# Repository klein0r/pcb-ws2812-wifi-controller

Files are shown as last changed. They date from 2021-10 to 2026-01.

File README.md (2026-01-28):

# WS2812 / SK6812 Wifi Controller Custom PCB

Control your addressable LED with custom software like [WLED](https://github.com/Aircoookie/WLED)

[Gerber-Files](https://github.com/klein0r/pcb-ws2812-wifi-controller/releases)

## Preview

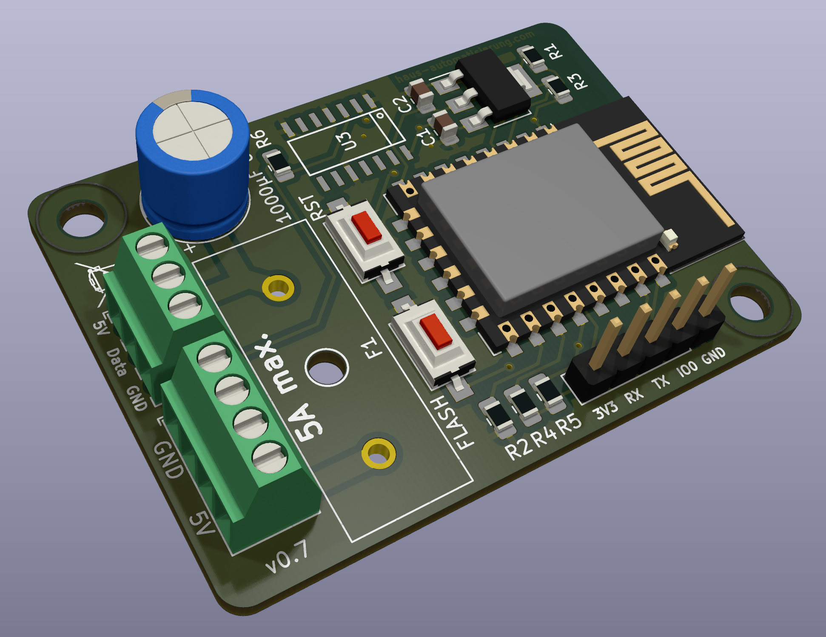
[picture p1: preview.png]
PCB Preview


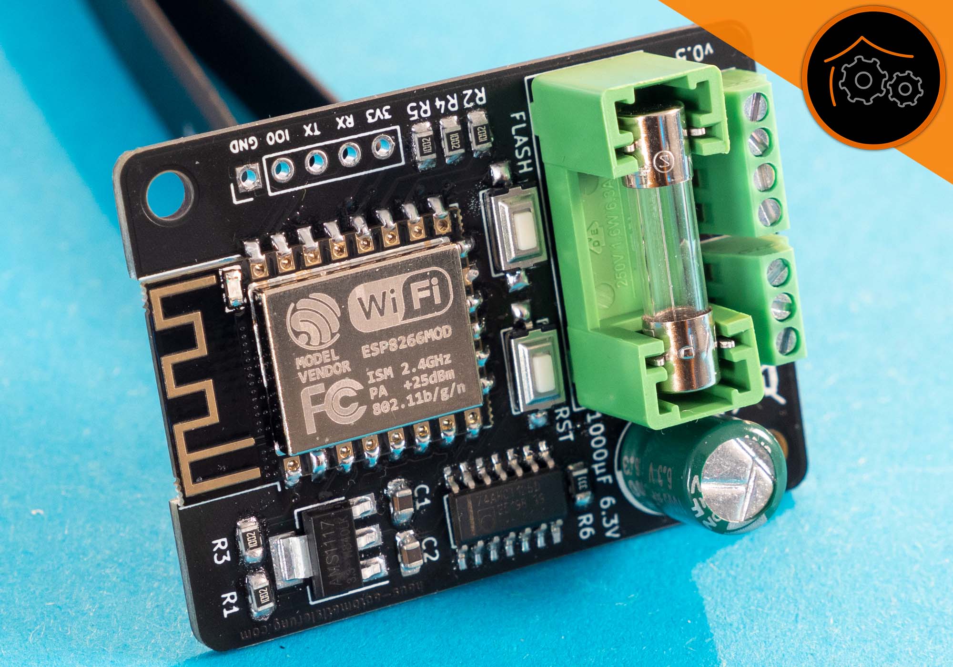
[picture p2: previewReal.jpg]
PCB Photo


## Components

- C1, C2: Capacitor 0805 100nF
- C3: Capacitor Radial 3.8mm 1000μF 6.3
- F1: Stelvio Kontek STV PTF/75 + Fuse 5x20mm, 5A (max. 6A)
- J1: PHC 1725672 - MPT 0,5 / 4-2,54
- J2: 1x5 2.54mm Male Pin Headers (for flashing - soldering not required)
- J3: PHC 1725669 - MPT 0,5 / 3-2,54
- R1, R2, R3, R4, R5: Resistor 0805 10k
- R6: Resistor 0805 330
- SW1, SW2: Push Button 3*6*2.5mm
- U1: AMS1117-3.3 SOT 223
- U2: ESP-12F
- U3: SN74AHCT125DR

## GPIO

- GPIO4 = Data line of addressable strip

## Cases

- [Case by DrNuke33](https://www.thingiverse.com/thing:4909109)

## Older Versions

*See git tag / releases*

**0.1**

PCB Preview

**0.2**

PCB Preview

**0.3**

PCB Preview

**0.4**

PCB Preview

## License

The MIT License (MIT)

Copyright (c) 2026 Matthias Kleine <info@haus-automatisierung.com>

Permission is hereby granted, free of charge, to any person obtaining a copy
of this software and associated documentation files (the "Software"), to deal
in the Software without restriction, including without limitation the rights
to use, copy, modify, merge, publish, distribute, sublicense, and/or sell
copies of the Software, and to permit persons to whom the Software is
furnished to do so, subject to the following conditions:

The above copyright notice and this permission notice shall be included in
all copies or substantial portions of the Software.

THE SOFTWARE IS PROVIDED "AS IS", WITHOUT WARRANTY OF ANY KIND, EXPRESS OR
IMPLIED, INCLUDING BUT NOT LIMITED TO THE WARRANTIES OF MERCHANTABILITY,
FITNESS FOR A PARTICULAR PURPOSE AND NONINFRINGEMENT. IN NO EVENT SHALL THE
AUTHORS OR COPYRIGHT HOLDERS BE LIABLE FOR ANY CLAIM, DAMAGES OR OTHER
LIABILITY, WHETHER IN AN ACTION OF CONTRACT, TORT OR OTHERWISE, ARISING FROM,
OUT OF OR IN CONNECTION WITH THE SOFTWARE OR THE USE OR OTHER DEALINGS IN
THE SOFTWARE.

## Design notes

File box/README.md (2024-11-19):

# Print parts 

## Preview

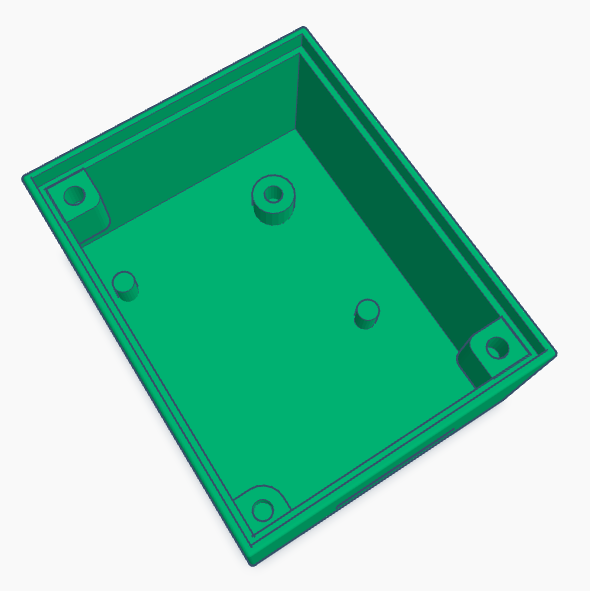
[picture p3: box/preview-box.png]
Box v3

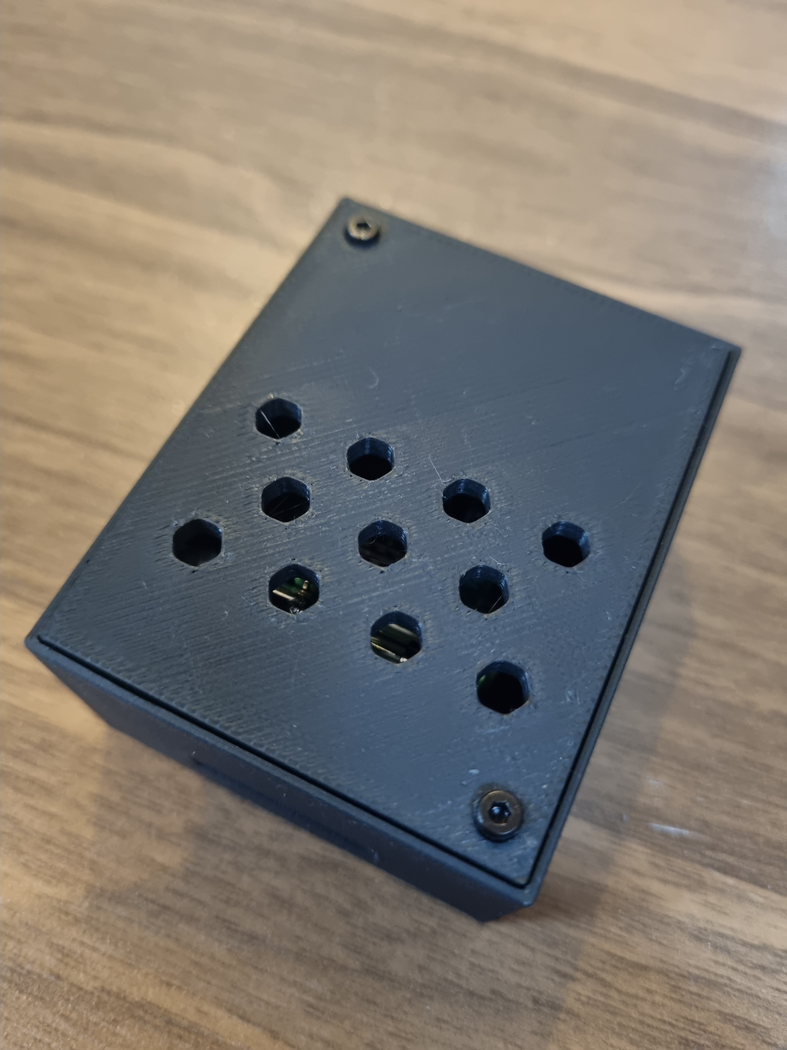
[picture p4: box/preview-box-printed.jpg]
Box printed


## Components

- 4x Melting nut M2x4.0
- 4x Screw M2x4

## Changelog

### 2024-05-17

#### Added

- box-v2 Base box model without supports for the board. When tighten the screws sometimes the board happens to tilt slightly
- box-v3 Improved version of v2, should stop the board from tilting. This model hasn't been prototyped yet
- box-cover-v2 A cover to close the box

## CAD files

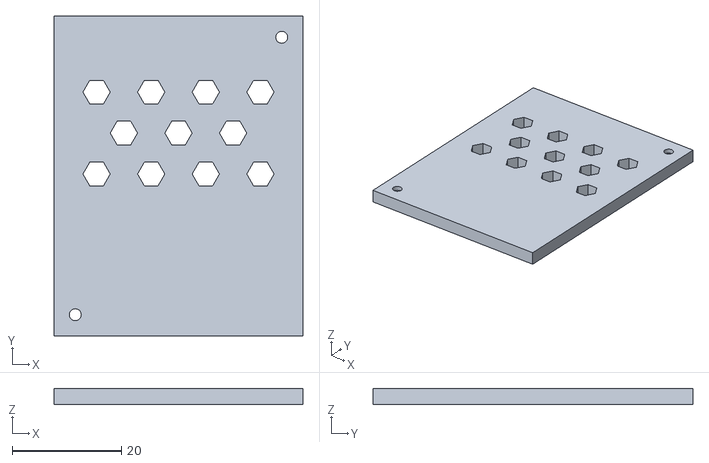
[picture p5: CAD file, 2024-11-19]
box/box-cover-v2.stl
45.6 x 58.6 x 3.00

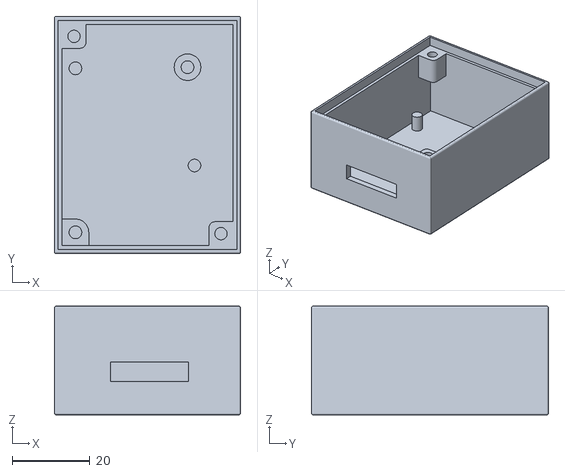
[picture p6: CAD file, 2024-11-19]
box/box-v3.stl
48.0 x 61.0 x 28.0

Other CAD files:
box/box-v2.stl

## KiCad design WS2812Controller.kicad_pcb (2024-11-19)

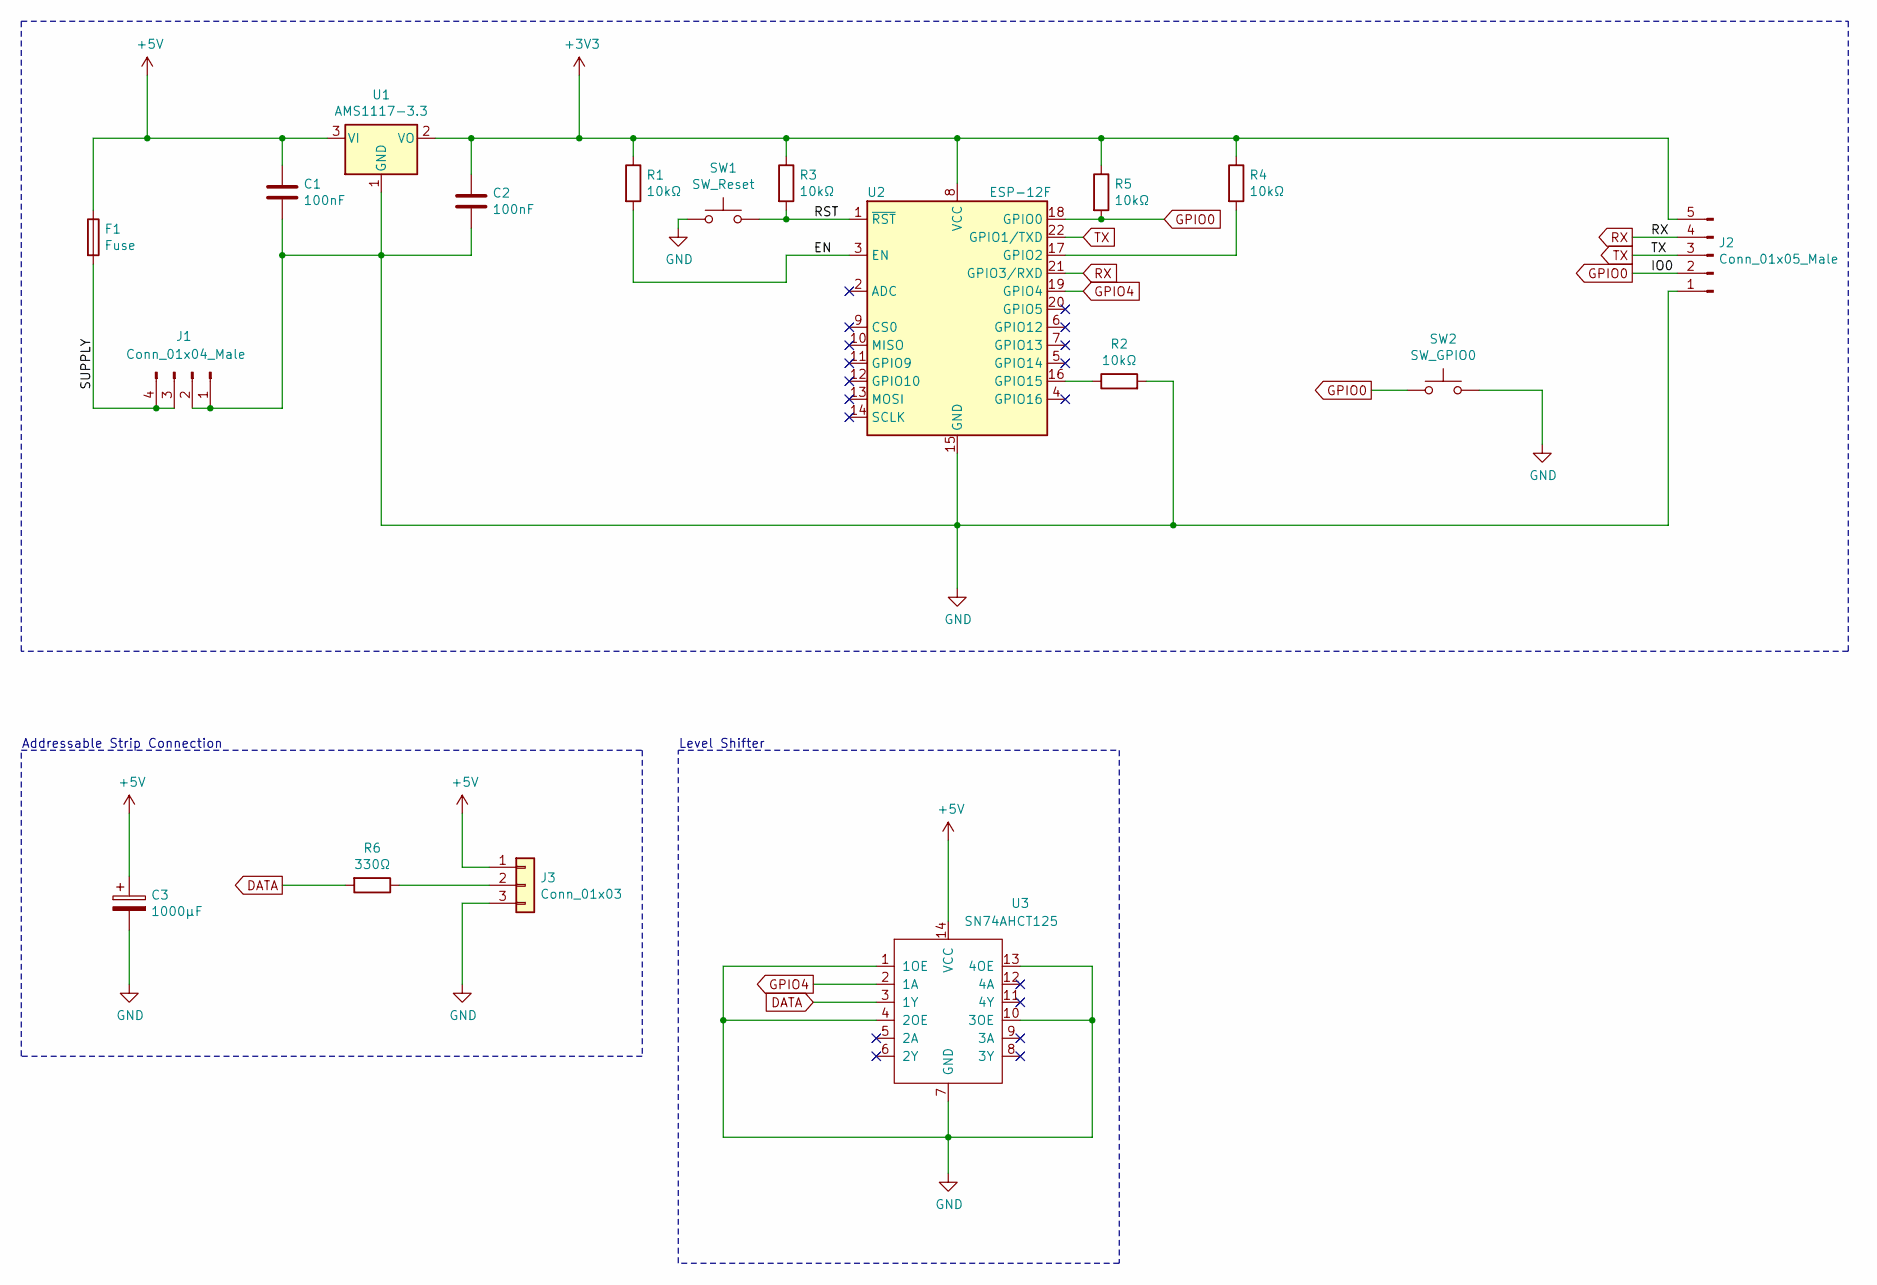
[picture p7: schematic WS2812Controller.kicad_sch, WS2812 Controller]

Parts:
C1, C2: 100nF; C_0805_2012Metric_Pad1.15x1.40mm_HandSolder
C3: 1000µF; CP_Radial_D8.0mm_P3.80mm
F1: Fuse; Fuse-PTF75_Stelvio
J1: Conn_01x04_Male; TerminalBlock_Phoenix_MPT-0,5-4-2.54_1x04_P2.54mm_Horizontal
J2: Conn_01x05_Male; PinHeader_1x05_P2.54mm_Vertical
J3: Conn_01x03; TerminalBlock_Phoenix_MPT-0,5-3-2.54_1x03_P2.54mm_Horizontal
R1, R2, R3, R4, R5: 10kΩ; R_0805_2012Metric_Pad1.15x1.40mm_HandSolder
R6: 330Ω; R_0805_2012Metric_Pad1.15x1.40mm_HandSolder
SW1: SW_Reset; SW_SPST_CK_RS282G05A3
SW2: SW_GPIO0; SW_SPST_CK_RS282G05A3
U1: AMS1117-3.3; SOT-223-3_TabPin2
U2: ESP-12F; ESP-12E
U3: SN74AHCT125; SN74AHCT125D

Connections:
+3V3: C2.1, J2.5, R1.1, R3.1, R4.1, R5.1, U1.2 (VO), U2.8 (VCC)
+5V: C1.1, C3.1, F1.1, J3.1, U1.3 (VI), U3.14 (VCC)
/EN: R1.2, U2.3 (EN)
/RST: R3.2, SW1.2, U2.1 (~RST)
/SUPPLY: F1.2, J1.3, J1.4
DATA: R6.2, U3.3 (1Y)
GND: C1.2, C2.2, C3.2, J1.1, J1.2, J2.1, J3.3, R2.2, SW1.1, SW2.2, U1.1 (GND), U2.15 (GND), U3.1 (1OE), U3.4 (2OE), U3.7 (GND), U3.10 (3OE), U3.13 (4OE)
GPIO0: J2.2, R5.2, SW2.1, U2.18 (GPIO0)
GPIO4: U2.19 (GPIO4), U3.2 (1A)
unnamed: J3.2, R6.1
unnamed: R2.1, U2.16 (GPIO15)
unnamed: R4.2, U2.17 (GPIO2)
RX: J2.4, U2.21 (GPIO3/RXD)
TX: J2.3, U2.22 (GPIO1/TXD)

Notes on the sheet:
Addressable Strip Connection
Level Shifter

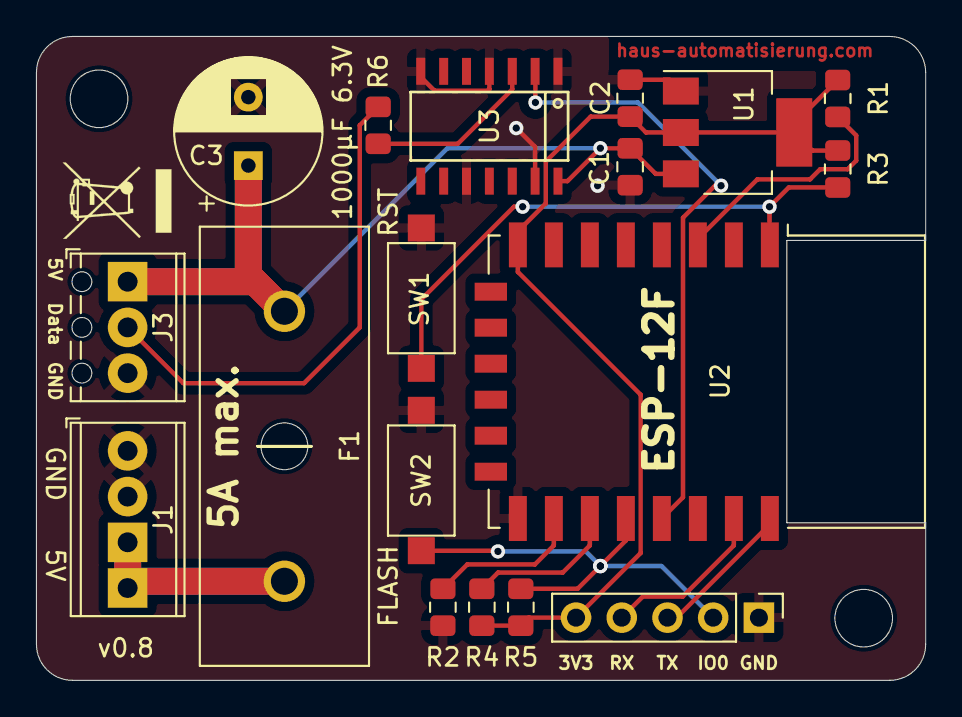
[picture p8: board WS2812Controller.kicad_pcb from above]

Board: 2 copper layers, 49.4 x 35.8 mm, 18 parts (0 on the bottom side), 14 nets.

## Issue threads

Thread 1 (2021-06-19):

some upgrades for the Board

MaBe15, 2021-06-19:
Hi @klein0r,
erstmal danke für die super Arbeit mit der Platine, ich werde mir ein paar fertigen lassen.
Mir sind einge Kleinigkeiten aufgefallen, die ich für meine eigene Bestellung geändert habe, vlt. möchtest du die ja auch ändern:

- Leiterbahnbreite für das Supply-Netz und 5V-Netz vergrößert. Die 0,5mm sind zu gering um die 5A führen zu können bis die Sicherung fällt. [IPC2221](https://www.multi-circuit-boards.eu/leiterplatten-design-hilfe/oberflaeche/leiterbahn-strombelastbarkeit.html)
- Stützkondensatoren für den ESP wie im Datenbaltt beschrieben
- Glättungskondensatoren des Linearreglers an die Werte im Datenblatt angepasst
[pcb-ws2812-wifi-controller-upgrade-main.zip](https://github.com/klein0r/pcb-ws2812-wifi-controller/files/6680438/pcb-ws2812-wifi-controller-upgrade-main.zip)

Ansonsten ist das eine super Platine, danke dafür.
Gruß
Marcus

MaikPerezHeide, 2021-07-06:
Hallo Marcus, ist  es möglich, in Deinem Entwurf, den ESP 12F einfach 1:1 gegen einen ESP32-WROOM32D auszutauschen, oder muss da ggf. noch etwas an der Verkabelung geändert werden? Ich bin neu in diesem Bereich, habe auch wenig Ahnung von Elektronik. Ich würde aber gerne den ESP32 für dieses Projekt verwenden. Vielen Dank im Voraus.
Gruß
Maik

MaBe15, 2021-07-06:
Hallo Maik,
wenn ich es auf die schnelle richtig gesehen habe, dann stimmen die mechanischen Abmessungen des ESP32-WROOM32D mit denen des ESP12F nicht überein. Auch die Anzahl PINs und die Pinbelegung ist nicht identisch. Ein 1:1 Austausch ist also nicht möglich. Du müsstest also den Schaltplan und das Routing auf dem PCB komplett überarbeiten.

Gruß
Marcus

Philip52, 2021-12-29:
@MaBe15
Hi. Danke für dein Update. Ich wollte es gerade bei jlcpcb in Auftrag geben aber die können die Datei nicht öffnen. Hattest du das Problem auch oder hab ich evtl n Fehler gemacht. Grüße
Philip

nocodeman55, 2022-02-16:
> Hallo Marcus, ist es möglich, in Deinem Entwurf, den ESP 12F einfach 1:1 gegen einen ESP32-WROOM32D auszutauschen, oder muss da ggf. noch etwas an der Verkabelung geändert werden? Ich bin neu in diesem Bereich, habe auch wenig Ahnung von Elektronik. Ich würde aber gerne den ESP32 für dieses Projekt verwenden. Vielen Dank im Voraus.
> Gruß
> Maik
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

Sorry i need to reply in English

I found this module ESP-C3-12F Module

This might work - it have the same size and is ESP32 - should drop in - but im not sure about the needed pins?

Closed 2021-12-29.

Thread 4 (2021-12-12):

Kurzes Update ?

Xorfee, 2021-12-12:
Hey gibt es eventuell ne Möglichkeit den GPIO4 pin auf gpio3 zu ändern ? Weil ich gerne die Platine mit diyhue betreiben möchte und die nur gpio3 unterstützen

klein0r, 2021-12-29:
Einfach selbst mit KiCad im Schema anpassen und exportieren.

Closed 2021-12-29.

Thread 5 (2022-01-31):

Assembly ?

bangboomben, 2022-01-31:
Hi,

newbie-question: do the boards come pre-assembled with all the parts ?
If not, do I require any extra file for JLCPCB ?

Cheers
Ben

klein0r, 2022-01-31:
I always order the plain PCB without parts and solder them on my own.

There is also a service where you can order pre-assembled PCB. But: I haven't provided a file in this repository which component belongs to which location in which orientation...

Closed 2022-01-31.

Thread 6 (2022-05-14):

SN74AHCT125DR and AMS1117-3.3 not/hardly available (looking for an alternative)

marcheffels, 2022-05-14:
Hallo zusammen,

vorab einen großen dank an Matthias für dieses tolle Projekt. Leider ist der "SN74AHCT125DR" und der "AMS1117-3.3" zurzeit
kaum oder nur sehr schwer (teuer, lange Lieferzeit) zu bekommen.

Durch verglichen Eigenschaften/Datenblätter glaube ich das der "AMS1117-3.3" durch den "NCP 1117 ST33T3G" ersetzt werden kann.

Beim "SN74AHCT125DR" fällt mir das Finden einer Alternative schwerer und hier bin ich auf Hilfe angewiesen.

Vielen Danke
Gruß Marc

Acey-yo, 2022-05-21:
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

Hallo zusammen und dir Marc,

ich war auch gerade am zusammenstellen der Hardware, aber ich bin auf das selbe Problem gestoßen wie du.
Der AMS1117-3.3 soll bei reichelt.de ab dem 23.06.2022 verfügbar sein, das wäre also kein Problem.

Aber leider bin ich auch auf das Problem mit dem SN74AHCT125DR gestoßen. Man könnte es zwar aktuell über Rochester Electronics bekommen, doch die haben eine min. abnahmemenge von 244 was mir dann doch etwas Zuviel des guten ist.

Gibt es da keine andere Alternative oder verändertes Board wo man dieses Teil nicht mehr benötigt?

Lg Toby

klein0r, 2022-05-22:
> Gibt es da keine andere Alternative oder verändertes Board wo man dieses Teil nicht mehr benötigt?

Das ist schon ein bisschen ironisch, weil ich bestimmt 20 Kommentare bekommen habe, dass die Platine ohne Level Shifter nix taugt 😄

In Version 0.4 ist die Komponente noch nicht drauf.

Acey-yo, 2022-05-22:
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

Hallo,

ich habe mir grade mal die Version 0.4 angesehen.
Dort ist doch auf der Rückseite auch ein [SN74AHCT125] verbaut. Oder ist der in der Version nicht von Bedeutung bzw irre ich mich?
Sry ich bin nicht gerade ein Experte was das Thema angeht :)

Lg

klein0r, 2022-05-22:
Dann wars die 0.3 🤔

Acey-yo, 2022-05-22:
Ok hätte man auch von alleine drauf kommen können....^^
Also in der v 0.3 ist es nicht verbaut. 👍 #

Vielen Dank

oggii-beep, 2024-08-02:
Hallo zusammen,

ich würde das Thema gerne nochmal aufgreifen zumindest für den SN74AHCT125DR.
Dieser ist mittlerweile gar nicht auf reichelt gelistet. Ich habe stattdessen diesen hier gefunden: 74HCT125D von Nexperia.

Datenblätter verglichen, Pinbelegung und Package sind gleich, so wie ich die Parameter verstanden habe sollte das funktionieren, da der Chip bei der Input Spannung mit TTL levels Kompatibel ist.

Das sollte dann sogar ohne Anpassung der Platine funktionieren oder?

klein0r, 2024-08-04:
> ich würde das Thema gerne nochmal aufgreifen zumindest für den SN74AHCT125DR.
> Dieser ist mittlerweile gar nicht auf reichelt gelistet.

War er glaube ich auch noch nie. Hatte den damals bei AliExpress bestellt.
Wenn der Footprint, Datenblatt usw, übereinstimmt, dann sollte das ja passen?! Habe ich selbst nicht genauer angeschaut.

oggii-beep, 2024-09-07:
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

Hier eine Rückmeldung, ich habe jetzt 3 Controller mit dem 74HCT125D von Nexperia gebaut, und alle funktionieren!
Meiner Meinung nach wäre es hilfreich alternative Komponenten in der Readme mit aufzuführen, gerade bei "seltenen" oder schwer verfügbaren Teilen.

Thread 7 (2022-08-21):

I2C Pins belegt

schmoizz, 2022-08-21:
Hallo,
ist es vielleicht möglich, dass du eine Version der Platine veröffentlichst, die nicht GPIO 4 nutzt da dieser für I2C benötigt wird? Ich würde die Platine gerne in einem Uhr Projekt nutzen und ein RTC Modul anschließen, aber das funktioniert nur wenn ich Pin 4 und 5 zur Verfügung habe. Und kannst du dann eventuell die Pins über einen Header bereitstellen?
Ich bin leider eine absolute Niete in Platinendesign.

Gruß Sebastian

klein0r, 2022-08-22:
Ja, es wäre von Anfang an schlauer von mir gewesen, GPIO2 (wie im WLED Standard vorgesehen) zu verwenden. Muss ich mal anpassen. Die Frage ist: Wie soll denn dann das RTC-Modul angeschlossen werden? Ich führe ja keine weiteren Pins nach außen (wie I2C)

schmoizz, 2022-08-22:
Das hätte ich dann einfach bissl Banjo Wire mäßig da hin gemurkst hehe

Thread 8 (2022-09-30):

LED Leiste leuchtet nicht

Semi156, 2022-09-30:
Moin Matthias,
eventuell haste nen Tipp für mich, ich verzweifle langsam. Hab den Controller zusammengebaut und geflasht, soweit funktioniert auch alles, wenn ich nun die LED Leiste anschließe, bleibt die einfach aus, egal welche Settings ich in WLED setze. Wenn ich GPIO 4 in den LED Settings wähle, dann bleibt die kleine Status LED am ESP auch einfach aus und es sieht so aus als würde da irgendwas nicht mehr funktionieren. Stelle ich den GPIO auf 2, brennt zwar die Status LED wieder, aber die LED Leiste bleibt weiterhin wie bei GPIO 4 einfach aus.

Wenn ich das gleiche Setup an einen D1 Mini anschließe, dann funktioniert alles wie es soll.

Bin für jeden Tipp Dankbar.

Liebe Grüße

Semi

jns80, 2024-07-25:
Hallo Semi,

ich habe tatsächlich das gleiche Problem wie du.
Gab es eine Lösung dazu?

Semi156, 2024-07-25:
Hi @jns80

leider nicht, hab's irgendwann aufgegeben und bin zurück zu den d1 Minis 😔

Hab Mega viele davon und kann aktuell nichts mit anfangen. Hoffe immer noch auf Hilfe

jns80, 2024-07-25:
Ok, schade.
@klein0r
Hast du evtl. eine Idee was unser Problem sein kann?

Viele liebe Grüße
Jens

klein0r, 2024-07-26:
Ist etwas schwer zu erkennen, aber ist der SN74AHCT125DR eventuell falsch rum?
Scheint auch ein anderes Modell zu sein, als meiner (andere Beschriftung).

Semi156, 2024-07-26:
Moin @klein0r

hab tatsächlich beides probiert, aber auf der Platine ist eingezeichnet wo der Strich sein muss. Auf Vermutung, dass die Markierung eventuell auf der falschen Seite ist, hab ich dann beides probiert, aber das hat leider auch nicht geholfen

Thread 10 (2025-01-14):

LED Leiste blinkt wild

bigsmoke373, 2025-01-14:
Ich habe die aktuellste Version des WLED Controller von klein0r und habe Probleme mit einem Teil meines LED-Strips. Ich habe vier Strips hintereinander von ca. je 1,6m länge. Pro Strip 95 LEDs. Die Strips sind seitlich an zwei Dachfenstern angebracht. Die Datenleitung habe ich entsprechend mit einem Kabel von Strip zu Strip geführt. Der letzte der 4 Strips macht Probleme, er zeigt nicht das an was er soll sondern blinkt teilweise wild. Liegt wahrscheinlich an der langen Datenleitung. Wenn ich den Strip direkt an den Controller anschließe funktioniert er wie er soll. Ich habe mal die Spannung der Datenleitung gemessen. Zwischen der Datenleitung und Massa habe ich direkt am Controller ca. 0,3V. Am Eingang vom 4 Strip nur 0,16V. Ich habe mich etwas belesen. Die Lösung soll ein Level Shifter sein. Hat der Controller von klein0r sowas schon einen Level Shifter verbaut und er funktioniert ggf. nicht richtig oder habe ich falsch gemessen? Nach meinen Recherchen sollte ich ca. 3,3 V an der Datenleitung messen, da das die Ausgangsspannung des ESP32 ist. An der 5V Spannungsversorgung des Strips liegt das Problem auf jeden Fall nicht. Da habe ich 4,9X Volt.

bigsmoke373, 2025-04-13:
Sorry für die späte Antwort. Durch den Umbau bin ich nicht früher dazu gekommen. Mich würde mal interessieren welche Spannung bei anderen zwischen Datenleitung und Masse anliegt.

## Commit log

2019-12-13 Initial version
    [WS2812Controller.kicad_pcb, WS2812Controller.sch]
2021-05-07 2019 -> 2021
    [WS2812Controller.kicad_pcb, WS2812Controller.sch]
2021-05-08 New layout
    [WS2812Controller.kicad_pcb, WS2812Controller.sch]
2021-05-08 Rounded edge cuts
    [WS2812Controller.kicad_pcb]
2021-05-08 Readme and Preview
    [WS2812Controller.kicad_pcb]
2021-06-21 Bigger tracks for 5V supply
    [WS2812Controller.kicad_pcb, WS2812Controller.sch]
2022-01-30 Updated to KiCad 6
    [WS2812Controller.kicad_sch, WS2812Controller.sch]
2022-01-30 Fixed minor connection issues
    [WS2812Controller.kicad_pcb, WS2812Controller.kicad_sch]
2023-08-16 Updated preview
    [WS2812Controller.kicad_pcb]
2024-05-17 Add 3d print box models
    [box-cover-v2.stl, box-v2.stl, box-v3.stl]
